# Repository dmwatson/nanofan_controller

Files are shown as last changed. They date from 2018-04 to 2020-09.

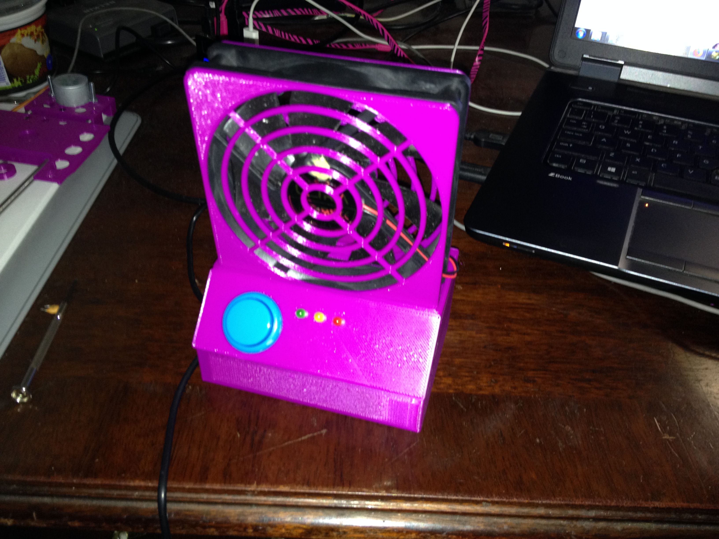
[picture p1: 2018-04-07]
images/IMG_1712.JPG

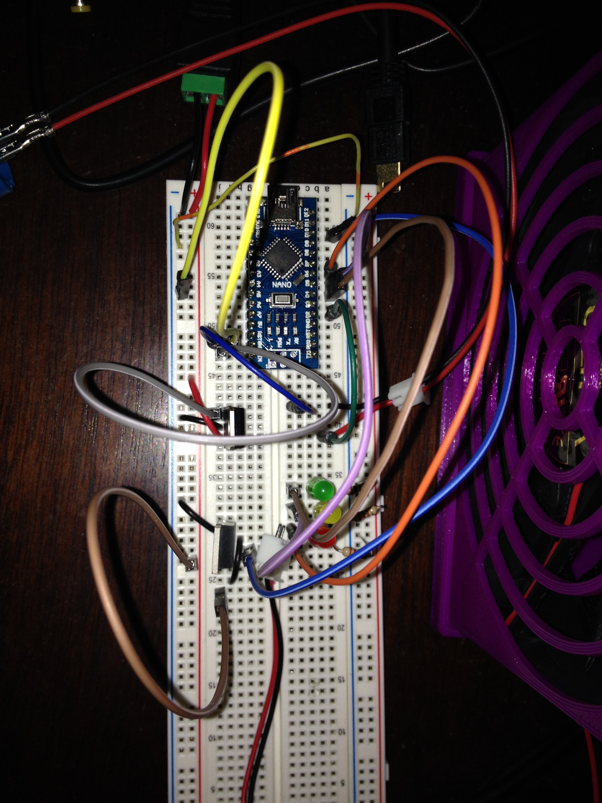
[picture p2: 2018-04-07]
images/IMG_1706.JPG

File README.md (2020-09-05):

# Nanofan Controller

Purpose: Control a fan using MOSFET and PWM with interrupts on an Arduino Nano.

There are countless tutorials out there on how to control a fan using PWM on an Arduino, some good and some bad. I wanted to explore how to do it with small, optimized code that ran as efficiently as possible. While this comes close at 1.4KB, I think it could be improved upon.

This design does not use a potentiometer to set fan speed. Rather, it uses a single arcade button that cycles through preset fan speeds then shuts off. And I wanted to do it through interrupts for the fastest possible response time.

Three LEDs are used to represent the different fan speeds. Green for slow, yellow for medium, and red for full speed. As speed increases, the LEDs graduate up until all 3 are lit at full speed.

### Motivation

While it may seem simplistic, I wanted to tackle this project from start to finish, including documentation and releasing on GitHub. Hopefully someone out there will learn from it.

### License

All source code, models, CAD files, etc., for this project are released under the MIT License.

### Bill of Materials

For this project, I used:

* (1x) Arduino Nano
* (1x) LM7805 Voltage Regulator
* (1x) 30N06LE N-channel MOSFET*
* (1x) 30mm Arcade Button
* (1x) 5mm Green LED
* (1x) 5mm Yellow LED
* (1x) 5mm Red LED
* (1x) 120mm 12V fan

The 30N06LE MOSFET is definitely overkill for this project, as it has a maximum rating of 60V. Any comparable N-channel MOSFET with a voltage rating greater than 12V and current output of at least 1A will work.

Note that you don't have to use green, yellow, and red LEDs. You can use any combination of colors. I picked these to be able to easily denote what speed the fan is at, even in the dark.

Included in this repository also are the STL files for the fan case for 3D printing, as well as the OpenSCAD source for modification. 

### Pins

The pins used on the Nano for this project are:

* D10 (PB2): MOSFET gate -- Used for PWM. Used in lieu of D3, D5, and D6 because Timer1 does not affect millis()
* D2 (PD2): Arcade button -- Pin change interrupt pin
* D4 (PD4): Green LED
* D5 (PD5): Yellow LED
* D6 (PD6): Red LED

### Compatibility

The code will work with an Arduino Nano, Uno, or even a barebones ATMega328P. With some understanding of the code, it could easily be ported to work with other microcontrollers in the Arduino family. 

### Models

Included in the repository are the STL files for a case designed to be 3D printed. It's a snap fit design so you can open it back up more easily and access the hardware. You can print it yourself also or give a go at the OpenSCAD source file to modify it.

The lid is recessed to hold the fan on top and will accommodate a 120mm fan with grilles. I used [this model](https://www.thingiverse.com/thing:263573) for my fan grilles.

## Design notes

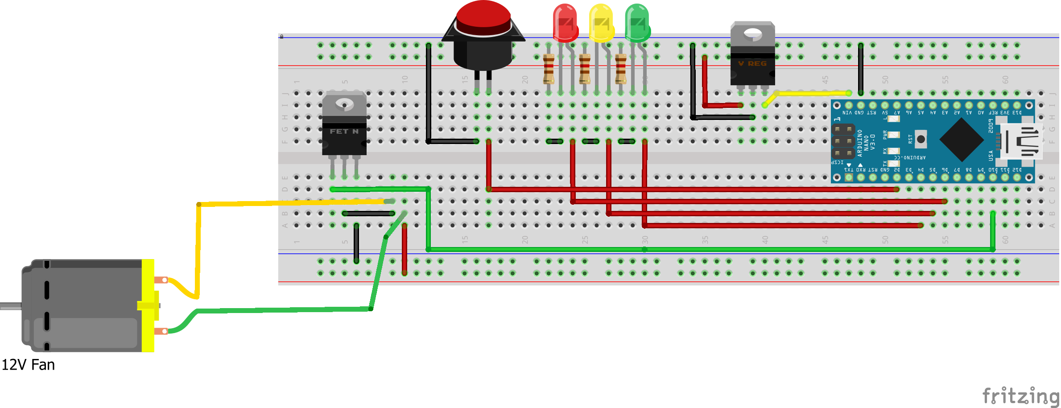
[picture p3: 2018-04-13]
schematic/Nanofan Controller_breadboard.png

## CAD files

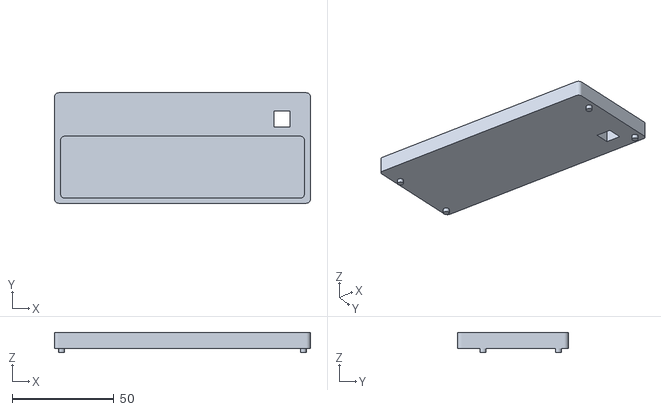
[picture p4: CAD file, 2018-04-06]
case/fan_lid.stl
126.0 x 54.4 x 10.0

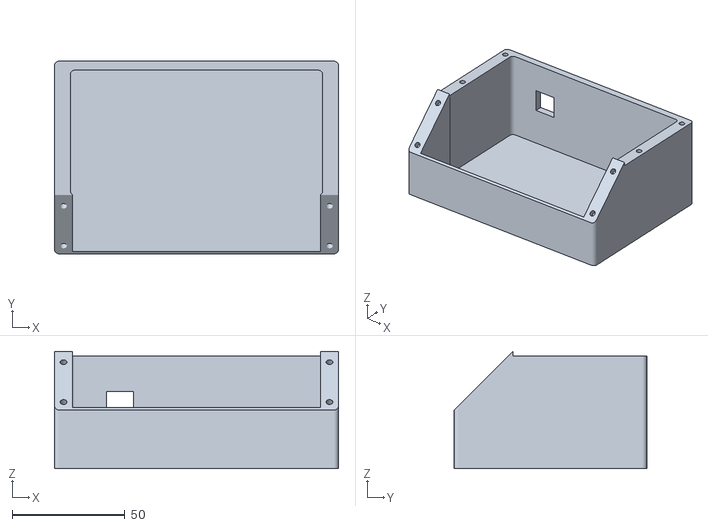
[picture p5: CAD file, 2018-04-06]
case/fan_base.stl
126.0 x 85.5 x 52.0

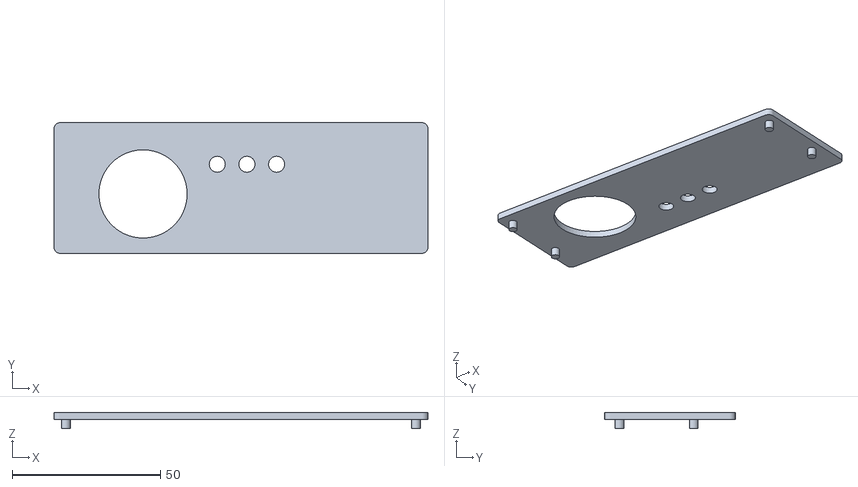
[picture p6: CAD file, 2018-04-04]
case/fan_faceplate.stl
126.0 x 44.0 x 5.40

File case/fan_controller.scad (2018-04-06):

/*
    120mm Fan Controller Case
    Author: Devin Watson
*/

/*
    Part numbers for individual models:
    
    0: Full assembly (viewing only)
    1: Case lower
    2: Faceplate
    3: Fan housing / top lid
*/
PARTNO = 1;

button_lower_dia = 29.7;
button_upper_dia = 32.8;
button_height = 24.9;
button_upper_height = 7.9;
led_dia = 5.4;
button_lower_height = button_height - button_upper_height;

fan_width = 120; // 120mm fan
fan_thickness = 30.5;   // 29.7mm thick
floor_thickness = 2.0;
case_height = 55;

$fn = 70;

module fan() {
    roundedcube(fan_width, fan_thickness, fan_width, 2);
}

// Makes a Sanwa style arcade button slug
module arcade_button() {
    union() {
        cylinder(d=button_lower_dia, h=button_lower_height);
        translate([0,0,button_lower_height]) cylinder(d=button_upper_dia,h=button_upper_height);
    }
}

module case_lower() {
    
    union() {
        
        difference() {
            translate([-3,-3, 0]) roundedcube(fan_width + 6, fan_thickness + case_height, case_height, 2);
            translate([-5,case_height/2 - 4.5,case_height - 7]) roundedcube(fan_width + 12, case_height + 10, 10, 2);
            
            // Power supply hole
            translate([20,fan_thickness + case_height,20]) rotate([90,0,0]) cube([12.15, 12.15, 10]);
            
            // Cutouts and curves
            translate([4,23,-5]) roundedcube(fan_width - 8, fan_thickness + 25, case_height + 2, 2);
            
            // 45-degree angle on front
            translate([-4,-64,6]) rotate([-45, 0, 0]) roundedcube(130, 30, 100, 2);
            
            // Angled cutout on front for faceplace
            translate([5,-2,-1]) cube([fan_width - 10, 25.75, case_height - 2]);
            
            translate([-3, -3, 24]) { 
                rotate([45, 0, 0]) {
                    faceplate();
                }
            }
            
            // Create pin holes
            fan_housing();
        }
        
        translate([-3, -3, -floor_thickness]) {
            bottom_plate();
        }
    }
}

// Top lid to hold the fan
module fan_housing() {
    union() {
        difference() {
            translate([-3,case_height/2,case_height - 7]) roundedcube(fan_width + 6, case_height - 0.6, 8, 2);
            // Fan slug
            translate([0,30,50]) fan();
       
            // Fan power wiring hole
            translate([105,65,10]) cube([8,8,60]);
        }
        
        // TL
        translate([0.5,case_height + 22, case_height-9]) {
            cylinder(d=3, h=3);
        }
        
        // BL
        translate([0.5,case_height - 15, case_height-9]) {
            cylinder(d=3, h=3);
        }
        
        // BR
        translate([fan_width - 0.5,case_height - 15, case_height-9]) {
            cylinder(d=3, h=3);
        }
        
        // TR
        translate([fan_width - 0.5, case_height + 22, case_height - 9]) {
            cylinder(d=3, h=3);
        }
    }
}

module faceplate() {
    led_x_offset = 55;
    
    union() {
        difference() {
            roundedcube(fan_width + 6, 44, 2.4, 2);
            translate([30, 20, -12]) arcade_button();
            
            // LED passthroughs
            translate([led_x_offset, 30, -1]) cylinder(d=led_dia, h=10);
            translate([led_x_offset + 10, 30, -1]) cylinder(d=led_dia, h=10);
            translate([led_x_offset + 20, 30, -1]) cylinder(d=led_dia, h=10);
            
        }
    
        // BL
        translate([4, 5, -3]) cylinder(d=3, h=3.5);
        
        // TL
        translate([4, 30, -3]) cylinder(d=3, h=3.5);
        
        // TR
        translate([fan_width + 2, 30, -3]) cylinder(d=3, h=3.5);
        
        // BR
        translate([fan_width + 2, 5, -3]) cylinder(d=3, h=3.5);
    }
}

module bottom_plate() {
    roundedcube(fan_width + 6, fan_thickness + 55, floor_thickness, 2);
}

module full_assy() {
    case_lower();
    
    translate([-3, -3, 24]) { 
        rotate([45, 0, 0]) {
            faceplate();
        }
    }
    
    fan_housing();
}

module roundedcube(xdim, ydim, zdim, rdim) {
    hull() {
        translate([rdim, rdim, 0]) cylinder(r=rdim,h=zdim);
        translate([xdim-rdim, rdim, 0]) cylinder(r=rdim,h=zdim);
        translate([rdim, ydim-rdim, 0]) cylinder(r=rdim,h=zdim);
        translate([xdim-rdim, ydim-rdim, 0]) cylinder(r=rdim,h=zdim);
    }
}

if ( PARTNO == 0 ) full_assy();
if ( PARTNO == 1 ) case_lower();
if ( PARTNO == 2 ) faceplate();
if ( PARTNO == 3 ) fan_housing();

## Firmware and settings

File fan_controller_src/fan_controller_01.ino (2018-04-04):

/* 
 *  Arduino Nano Fan Controller
 *  Version: 1.0
 *  Author: Devin Watson
 *  Purpose: Control a fan using MOSFET and PWM with interrupts
 *  Uses a 3-speed toggle to control fan speed with a button
 * 
 * Note: This uses a lot of direct port register manipulation for speed and size. If you want to use
 * a different set of pins, be sure to consult the datasheet for the correct PORT and DDR registers!
 * 
 * PWM timer frequencies that can be set based on the clock divider:
 * 
 * 1: 31372.5 Hz
 * 2: 3921.57 Hz
 * 3: 980.392 Hz
 * 4: 490.196 Hz (default)
 * 5: 245.098 Hz
 * 6: 122.549 Hz
 * 7: 30.6373 Hz
 * 
 * The controller uses Timer1's  Timer/Counter Control Register (TCCR1B) which uses pin D10 (PB2) on the Nano
 * For the fan that I use, 31372.5 Hz produces the best results without any  whining at any speed from the 
 * fan motor. Your mileage may vary depending on the fan you use.
 * 
 * Bill of Materials:
 * 
 * 1x Arcade button, 30mm
 * 1x LM7805 Voltage Regulator
 * 1x 30N06LE N-channel MOSFET, or any comparable N-channel MOSFET with a voltage rating greater than 12V and at least 1A
 * 1x 120mm 12V PC fan
 * 3x LEDs (any color)
 * 3x 120 ohm resistors
 * 1x 12V 2A power supply
 */

#define FAN_GATE  10  // D10 (PB2), utilizing the phase-correct PWM by default on Timer1
#define BUTTON_PIN 2  // D2 (PD2), one of the only pins on the Nano that has an interrupt
#define LED_PIN 4   // Starting pin for the 3 status LEDs (D4-D6)

volatile unsigned int fanSpeed = 0;

void setup() {
  // Set the PWM frequency to 31372.5 Hz
  // See comments at the top for all frequency values
  // This is for Timer1 register, which is where pin D10 (PB2) resides 
  TCCR1B = (TCCR1B & 0xF8) | 1;
  
  // Set the MOSFET gate pin to output
  DDRB &= ( 1 << PORTB2 );

  // Set all of the LED pins as output in one go
  DDRD = 0b01110000;

  // Button (D2) needs its pullup resistor turned on
  PORTD |= (1 << PORTD2);

  // Turn off the fan
  PORTB &= ~(1 << PORTB2);

  // Make sure the LEDs are turned off
  PORTD &= ~(1 << PORTD4) & ~(1 << PORTD5) & ~(1 << PORTD6);
  
  // Set up the interrupt for D2, which uses INT0
  attachInterrupt( 0, button_isr, FALLING );
}

void loop() {
  /* Nothing to do here. All the work is in the ISR */
}

void button_isr() {
  static unsigned long debounceTime;
  static int i;
  
   if ( millis() - debounceTime >= 250 ) {
      debounceTime = millis();
      fanSpeed = (fanSpeed + 85 > 255) ? 0 : fanSpeed + 85;
      
      PORTD &= ~(1 << PORTD4) & ~(1 << PORTD5) & ~(1 << PORTD6);

      for ( i = 0; i < (fanSpeed / 85) + 4; i++ ) {
        PORTD |= (1 << i); // Fast set LED pin high
      }

      // Set the fan speed
      analogWrite( FAN_GATE, fanSpeed );
    }
  
}

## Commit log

2018-04-06 Case design and models
    [fan_base.stl, fan_controller.scad, fan_lid.stl]
2018-04-10 README updated
    Added pin description.
2018-04-13 Breadboard schematic added
2018-04-13 Logical schematic added
2018-04-13 Updated schematic
    Updated schematic with power supply.
